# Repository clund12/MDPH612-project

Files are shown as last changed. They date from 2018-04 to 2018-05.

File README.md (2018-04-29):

MDPH612 TERM PROJECT
====================

# Towards a 4D breast phantom for Radiotherapy QA
## Translation of breathing trace data into mechanical motion

### Project Outline

The goal of this work is to design an open-source, easy-to-construct 4D breast phantom model that could be constructed by medical physicists for motion-tracking and, potentially, dosimetry of CyberKnife treatments.  A list of materials required by any interested physicists is provided below, as are the scripts needed to interact with the equipment and the files needed for the 3D printing of some components.  Initially, the goal is to construct a proof-of-principle 2D model that accurately translates the time and spatial (1D) information of a Varian RPM breathing trace into mechanical motion.

### Equipment

- Raspberry Pi 3
- NEMA 17 Stepper motor
- Archimedes screw, washer, and connector to motor
- Bearing to hold screw at other end
- Texas Instruments DRV8825 Stepper Motor Controller IC
- 3D printer capable of printing parts up to approximately 30 cm in length
- Electrical components:
    - 10-12 V power supply
    - Multimetre
    - Breadboard, wires, etc.

### Aims

- Write a script to control the motor via the RPi
- Connect the electronics, RPi, and motor and test the script
- Design a 3D model of the support and rails needed to house the mechanical
  components
- Assemble mechanics/electronics with housing and connect motor to screw
- Improve script to handle errors and make it more user-friendly
- Extend principles to include a second spatial dimension
- Still to come..

### Progress

- All electronics, mechanical, and printed components assembled properly
- The script interfaces the RPi, driver, and motor correctly
    - Able to handle complex input behaviour
    - Spatial accuracy is very high
    - Platform cannot be extended past the physical bounds of the rails and is
      always returned to the centre
    - Useful errors are returned when users input improper files

### Issues

- Temporal accuracy must be addressed
- Friction along the rails must be reduced
- Errors should be returned when movements are beyond the capacity of the motor
- Next iteration of housing will need to be made more robust

### Authors

- Chris Lund
- Veng Jean Heng

### Acknowledgements

- Dr. Francois DeBlois
- McGill MPU
- rdagger68 (circuitry tutorial)

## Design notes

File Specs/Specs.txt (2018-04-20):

Screw's spec:
(https://www.pololu.com/product/2268/specs)
Pitch = 2 mm, 4 Threads -> 8 mm per rotation
Pin of motor: (https://i.stack.imgur.com/2vYSy.png)
https://www.pololu.com/product/2688/pictures

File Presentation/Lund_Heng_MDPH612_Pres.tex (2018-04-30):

\documentclass{beamer}
\usetheme{CambridgeUS}
%\usecolortheme[RGB={0,0,0}]{structure}
\usepackage{pgfpages}
\usepackage{hyperref}
\usepackage{pdfpc-commands}
\usepackage{epstopdf}
\usepackage{array}
\usepackage{svg}
\usepackage{graphicx}
\usepackage{amsmath}
\usepackage{amsfonts}
\usepackage{amssymb}
\usepackage{bm}
\usepackage{ulem}
\usepackage{xfrac}
\usepackage{dcolumn}
\usepackage{multirow}
\usepackage{caption}
\usepackage{color}
\usepackage{listings}
\usepackage{gensymb}
\usepackage{appendixnumberbeamer}
\usepackage{animate}
%\setbeameroption{show notes}
%\setbeameroption{show notes on second screen=right}
\setbeamertemplate{bibliography item}[text]
%\renewcommand{\arraystretch}{1.5}
\newcommand{\mytilde}{\raise.17ex\hbox{$\scriptstyle\mathtt{\sim}$}}
\title[4D Breast Phantom]{Towards a 4D Breast Phantom for Radiotherapy QA}
\author[C. Lund, V.J. Heng]{Chris Lund and Veng Jean Heng}
\titlegraphic{}
\institute[McGill MPU]{Medical Physics Unit \\ Department of Oncology, McGill University}
\date{\today}
%\logo{\includegraphics[scale=0.2]{/home/chris/Documents/McGill/MDPH603/McGill_logo.png}}

\begin{document}

\begin{frame}

    \maketitle

\end{frame}

\begin{frame}

    \frametitle{Motivation}

    \begin{columns}
        \begin{column}{0.5\textwidth}
            \begin{itemize}
                \item Motion in imaging and treatment can pose an issue..
                    \begin{itemize}
                        \item Breath hold/gated treatments
                        \item CyberKnife motion-tracking
                        \item Motion artifacts in IGRT
                    \end{itemize}
                \vspace{1em}
                \item Currently, only available QA phantom is by QUASAR
                    \begin{itemize}
                        \item Very expensive
                        \item Not full 4D capabilities
                    \end{itemize}
                    \vspace{1em}
                \item Desire for more accessible alternative
            \end{itemize}
        \end{column}
        \begin{column}{0.5\textwidth}
            \vspace*{-1.5em}
            \begin{figure}[h]
                \centering
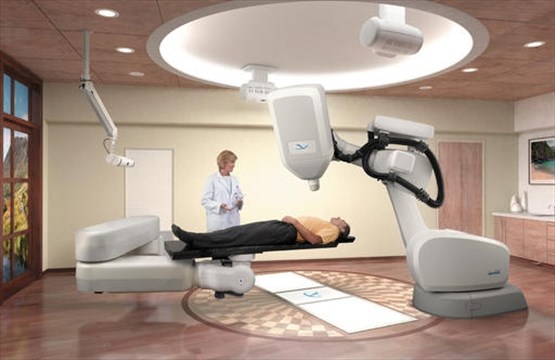
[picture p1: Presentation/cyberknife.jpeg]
                
            \end{figure}
            \vspace*{-2em}
            \begin{figure}[h]
                \centering
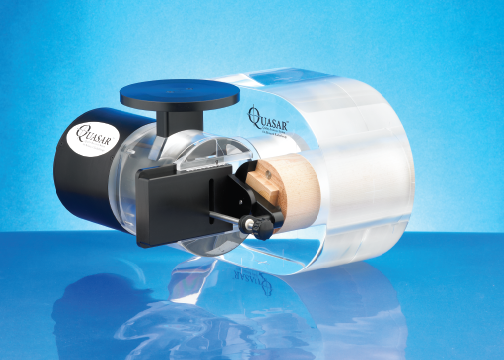
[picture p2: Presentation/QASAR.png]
                
            \end{figure}
        \end{column}
    \end{columns}

\end{frame}

\begin{frame}

    \frametitle{Overview of Project}

    \begin{itemize}
        \item Want to
            \begin{itemize}
                \item Take in a breathing trace
                \item Convert it into mechanical motion
            \end{itemize}
            \vspace{1em}
        \item Needs to be
            \begin{itemize}
                \item Standalone
                \item ``Perfect'' temporal and spatial accuracy
                \item Open-source and cheap
            \end{itemize}
            \vspace{1em}
        \item How to?
            \begin{itemize}
                \item Raspberry Pi $\rightarrow$ Stepper motor
                \item Rotational motion $\rightarrow$ Linear motion
            \end{itemize}
    \end{itemize}

\end{frame}

\begin{frame}

    \frametitle{Circuitry}

        \begin{figure}
            \centering
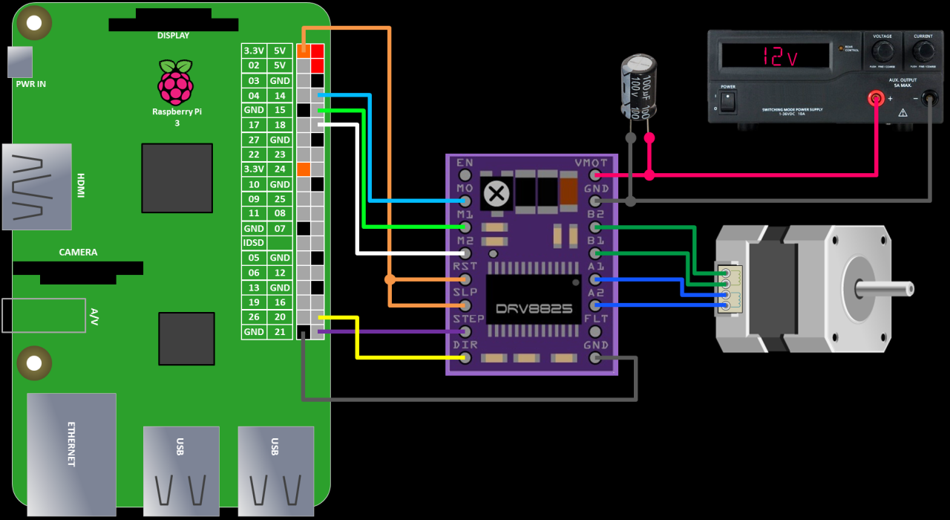
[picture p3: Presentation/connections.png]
            
        \end{figure}

\end{frame}

\begin{frame}

    \frametitle{Stepper Motors}
    \begin{columns}
        \begin{column}{0.5\textwidth}

            \begin{itemize}
                \item Step-based
                    \begin{itemize}
                        \item Define the angle of rotation
                        \item Perfect spatial accuracy
                    \end{itemize}
                    \vspace{1em}
                \item PWM-based
                    \begin{itemize}
                        \item Define the frequency of rotation
                        \item Perfect temporal accuracy
                    \end{itemize}
            \end{itemize}
        \end{column}
        \begin{column}{0.5\textwidth}
            \begin{figure}
                \centering
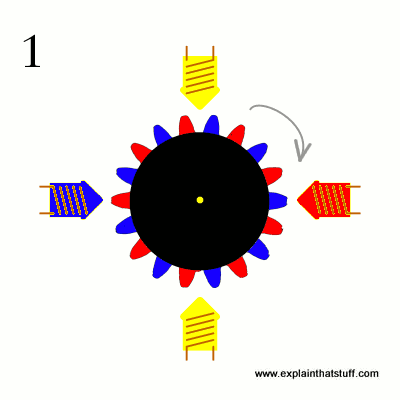
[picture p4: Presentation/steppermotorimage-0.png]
                
            \end{figure}
            \begin{figure}
                \centering
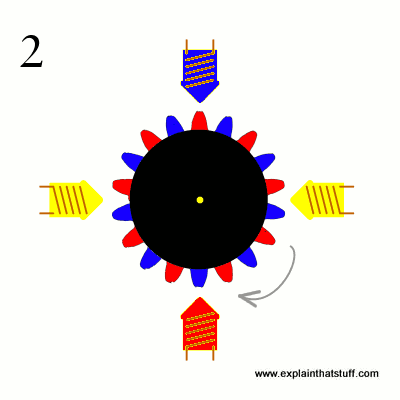
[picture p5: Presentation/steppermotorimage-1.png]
                
            \end{figure}
        \end{column}
    \end{columns}

\end{frame}

\begin{frame}

    \frametitle{Visit our page!}

    \centering
    \url{https://github.com/clund12/MDPH612-project}

\end{frame}

\end{document}

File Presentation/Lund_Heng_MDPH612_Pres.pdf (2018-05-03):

## Towards a 4D Breast Phantom for Radiotherapy QA

Chris Lund and Veng Jean Heng

Medical Physics Unit
Department of Oncology, McGill University

April 30, 2018

C. Lund, V.J. Heng (McGill MPU) | 4D Breast Phantom | April 30, 2018 | 1 / 6

## Motivation

Motion in imaging and
treatment can pose an issue.. Breath hold/gated treatments CyberKnife motion-tracking Motion artifacts in IGRT

Currently, only available QA phantom is by QUASAR
Very expensive
Not full 4D capabilities

Desire for more accessible alternative

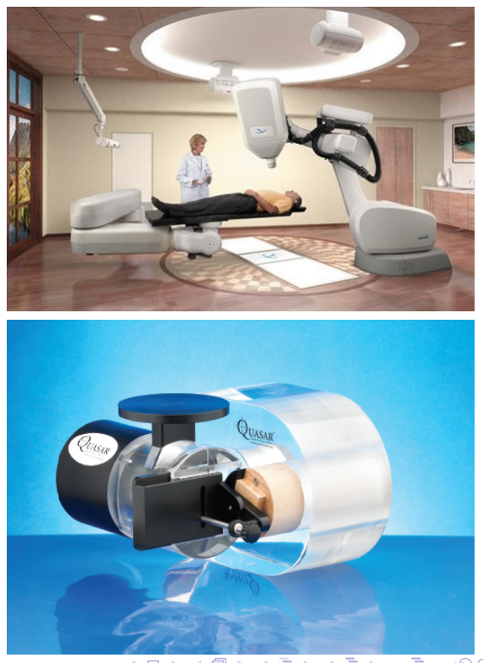
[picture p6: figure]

C. Lund, V.J. Heng (McGill MPU) | 4D Breast Phantom | April 30, 2018 | 2 / 6

## Overview of Project

Want to
Take in a breathing trace
Convert it into mechanical motion

Needs to be
Standalone
“Perfect” temporal and spatial accuracy Open-source and cheap

How to?
Raspberry Pi → Stepper motor Rotational motion → Linear motion
C. Lund, V.J. Heng (McGill MPU) | 4D Breast Phantom | April 30, 2018 | 3 / 6

## Circuitry

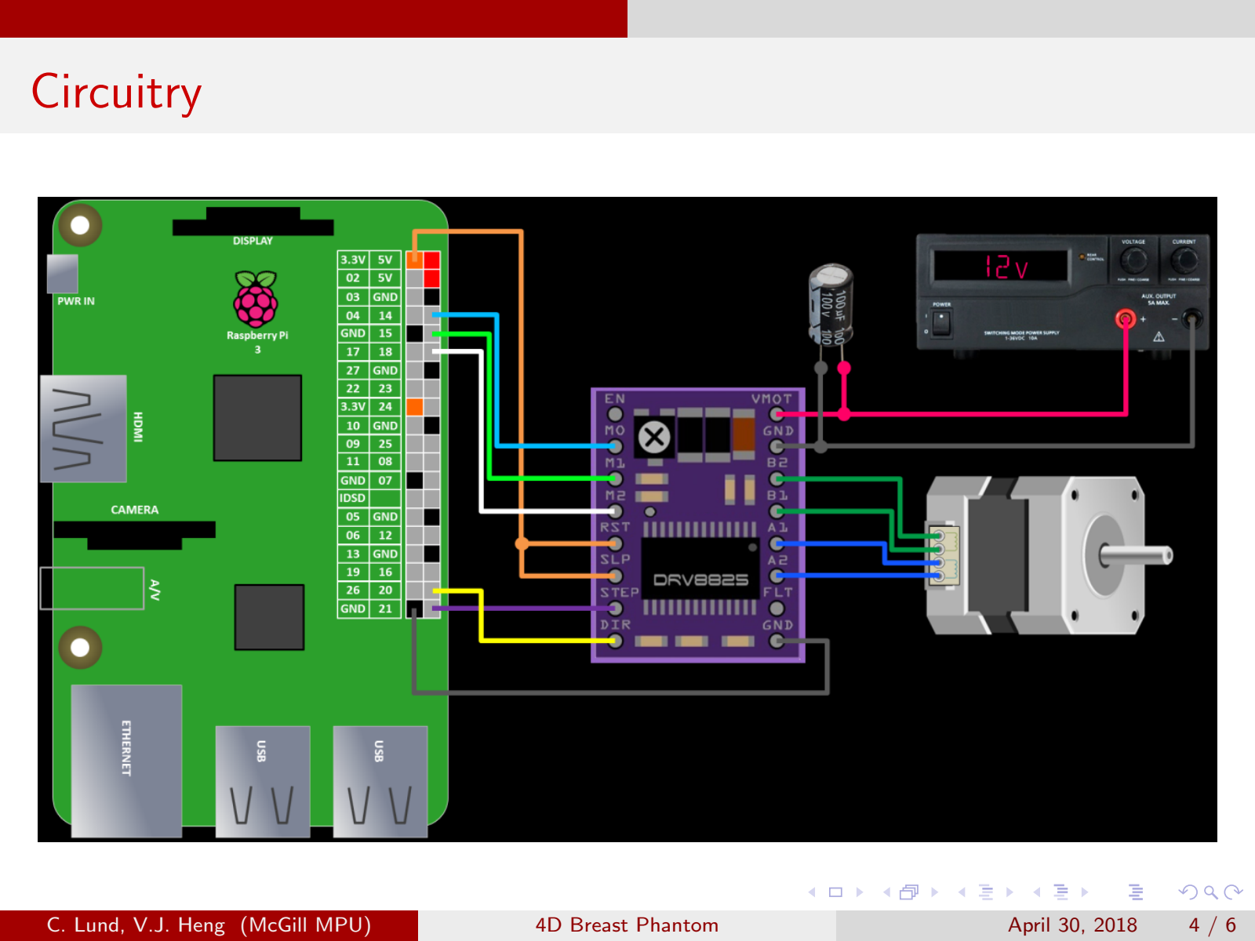
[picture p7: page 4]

C. Lund, V.J. Heng (McGill MPU) | 4D Breast Phantom | April 30, 2018 | 4 / 6

## Stepper Motors


Step-based
Define the angle of rotation Perfect spatial accuracy

PWM-based
Define the frequency of
rotation
Perfect temporal accuracy

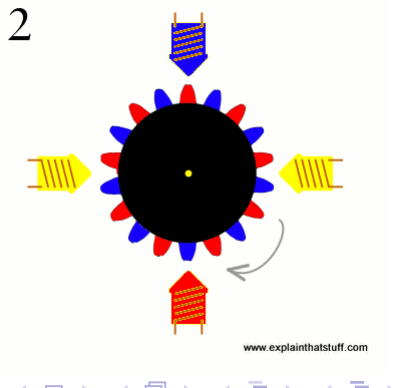
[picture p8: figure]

C. Lund, V.J. Heng (McGill MPU) | 4D Breast Phantom | April 30, 2018 | 5 / 6

## Visit our page!

https://github.com/clund12/MDPH612-project

C. Lund, V.J. Heng (McGill MPU) | 4D Breast Phantom | April 30, 2018 | 6 / 6

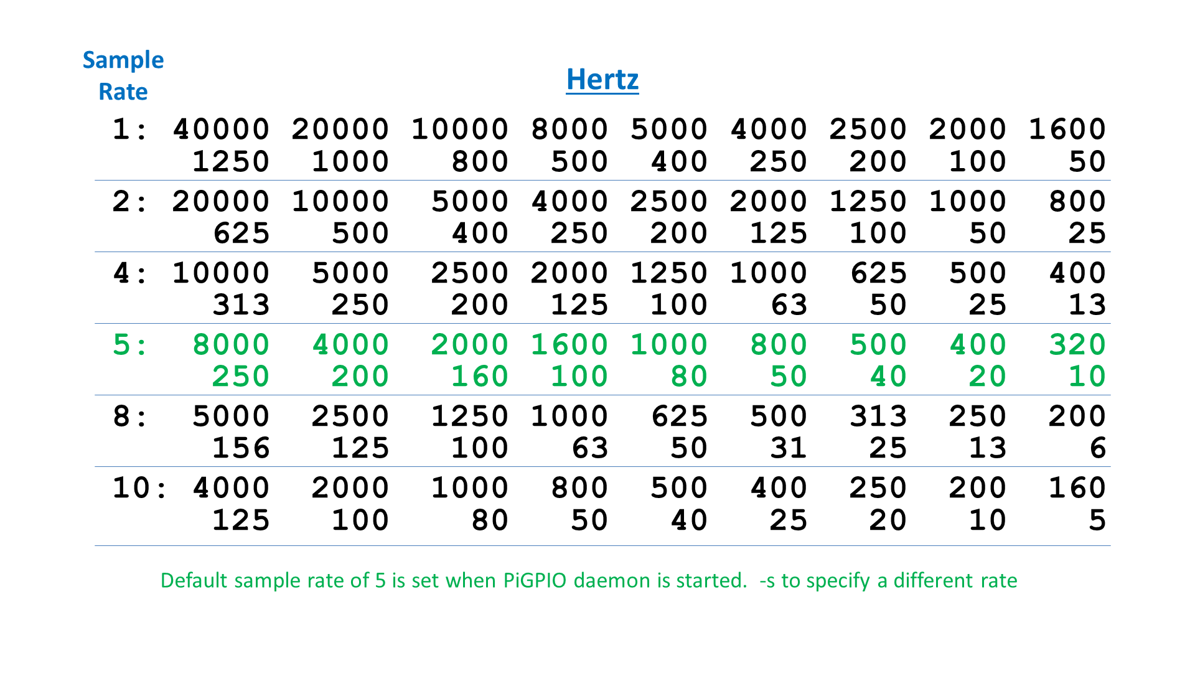
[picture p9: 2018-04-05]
Specs/PiStepperFreq.png

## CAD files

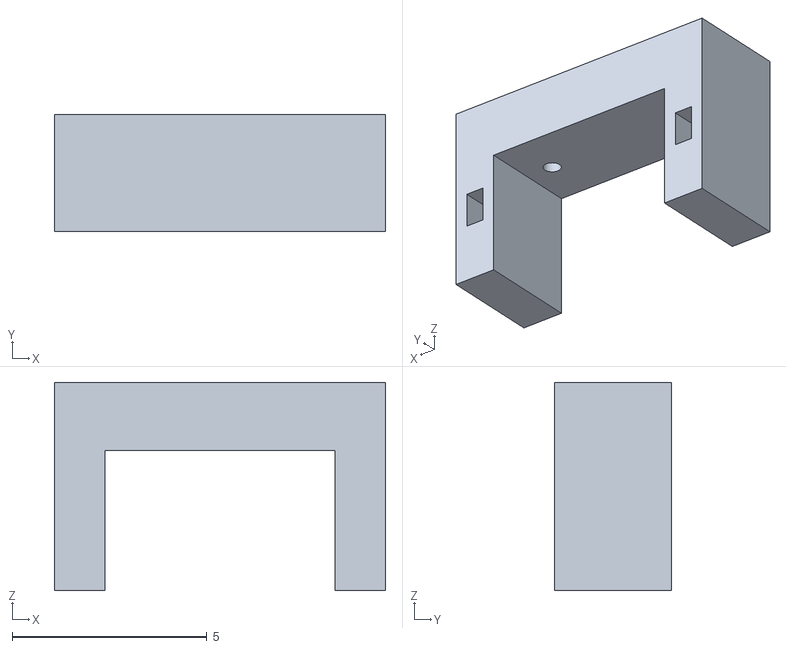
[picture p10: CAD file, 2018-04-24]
3D-Model/BearingCase.stl
8.50 x 3.00 x 5.35

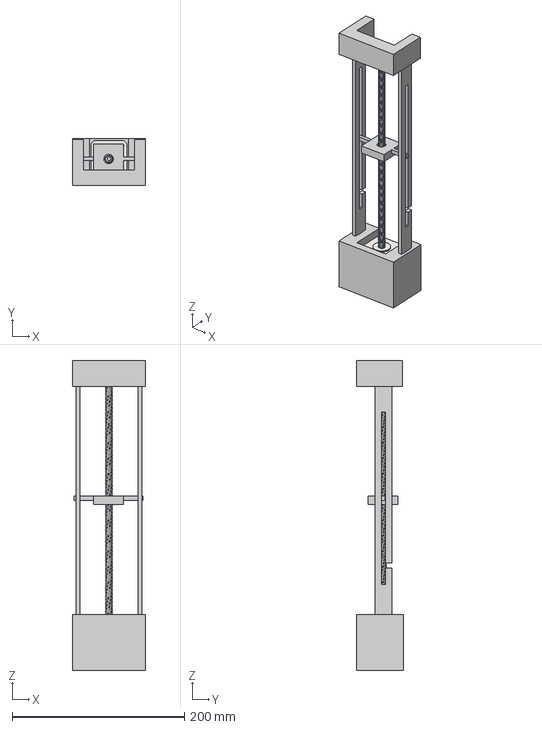
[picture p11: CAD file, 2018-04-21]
3D-Model/Combined v5.iges
85.0 x 55.0 x 360.0 mm

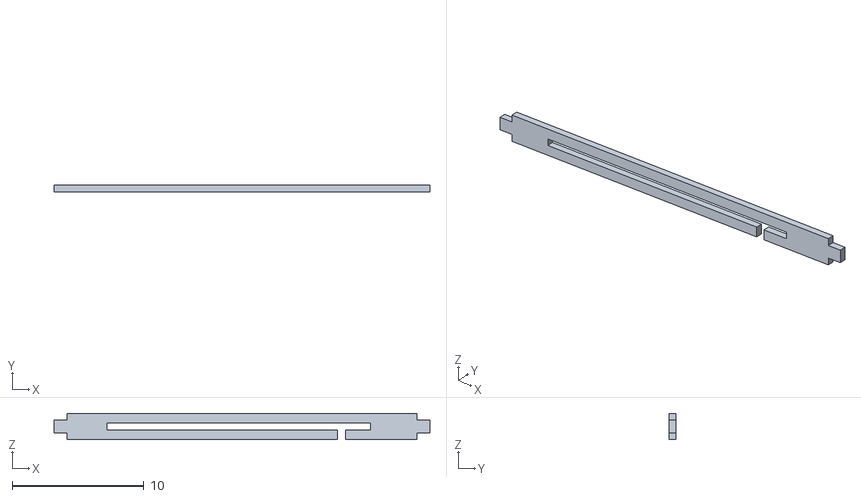
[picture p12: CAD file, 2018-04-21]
3D-Model/Rail.stl
28.5 x 0.5 x 2.00

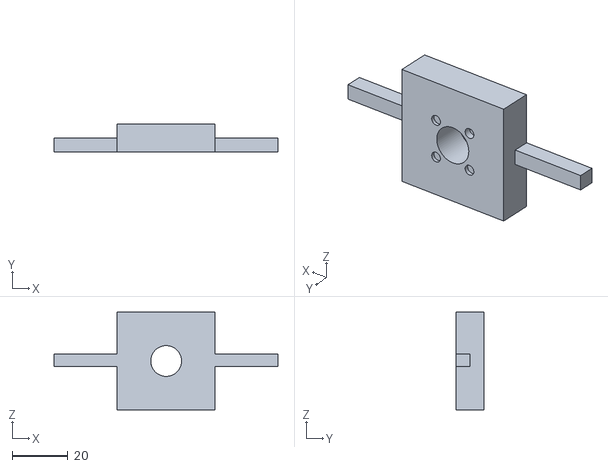
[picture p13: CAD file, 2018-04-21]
3D-Model/TravellingNut.stl
80.0 x 10.0 x 35.0

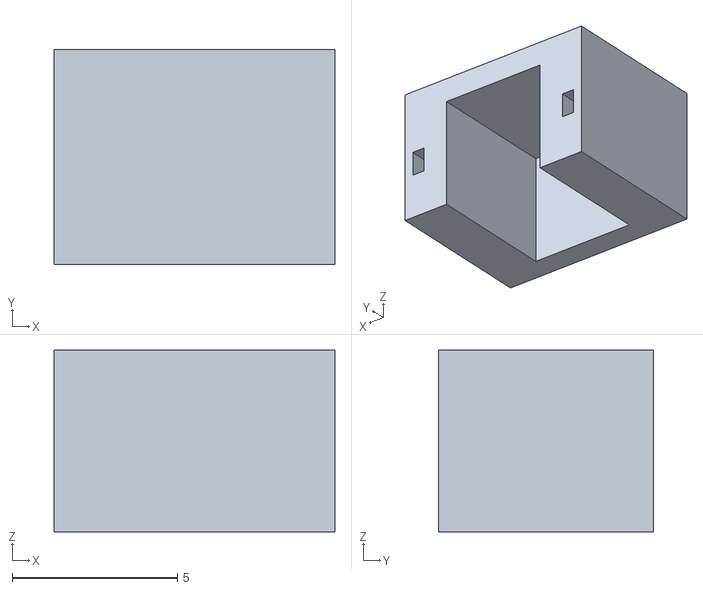
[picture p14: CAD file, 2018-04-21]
3D-Model/MotorCase.stl
8.50 x 6.50 x 5.50

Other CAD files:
3D-Model/Bearing Case v15.f3d
3D-Model/Motor casing v5.f3d
3D-Model/TravelingNut v5.f3d
3D-Model/rail.f3d

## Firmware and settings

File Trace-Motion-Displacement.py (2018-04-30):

import sys
import numpy as np
import csv
import itertools
import RPi.GPIO as GPIO
from time import time,sleep

#### This file must be run with a data file 
#### e.g. >> python FiletypeInputTest.py example.txt

##############################################################################
#### Set up GPIO pins and microstep resolution

# Convert direction from +/- to 1/0 for clockwise/counter-clockwise
def rot_direct(x):

    if np.sign(x) == 1:
        return 1
    else:
        return 0


DIR = 20          # Direction GPIO Pin
STEP = 21         # Step GPIO Pin
MODE = (14,15,18) # Microstep Resolution GPIO pins

GPIO.setmode(GPIO.BCM)      # Broadcom memory
GPIO.setup(DIR, GPIO.OUT)   # Sets direction pin to an output
GPIO.setup(STEP, GPIO.OUT)  # Sets step pin to an output
GPIO.setup(MODE, GPIO.OUT)


RESOLUTION = {'1': (0,0,0),
        '0.5': (1,0,0),
        '0.25': (0,1,0),
        '0.125': (1,1,0),
        '0.0625': (0,0,1),
        '0.03125': (1,0,1)}
RES = '0.25'

GPIO.output(MODE,RESOLUTION[RES])

################################################################################
# Read in data file, ensures it is a 2 column csv or txt file with equal lengths
# Import the data if it matches the criteria, raise an error otherwise
# PLEASE DELETE ANY AND ALL HEADERS

# First, read in data file entered during function call
f = open(sys.argv[1],'r')


# Check file extension in a case-insensitive manner
if sys.argv[1].lower().endswith('.csv'):
        
    # If .csv, use commas to split values and lines
    d = ','


elif sys.argv[1].lower().endswith('txt'):

    # If .txt, use tabs to split values and lines
    d = '\t'

    # Remove blank lines
    lines = f.readlines()

    with open(sys.argv[1],'w') as f:
        lines = filter(str.strip, lines)
        f.writelines(lines)


else: 
    raise ValueError("This is not a .csv or .txt file")

with open(sys.argv[1],'r') as f:

    # Use csv reader tool to make sure the number of columns is 2
    # Itertools.tee splits the single iterable output by csv reader into
    # multiple iterables
    rows, columns = itertools.tee(csv.reader(f, delimiter=d,
        skipinitialspace=True))


    # Read first line and count columns 
    if len(next(rows)) == 2:
        # Go back to beginning of file
        f.seek(0)

        # The file gives a list of values like ['t1,z1\n','t2,z2\n',etc.]
        # Where t = time (s), z = cranial-caudal displacement (cm)
        # Create new list of (t1,z1),(t2,z2), etc. tuples
        tz = []
        for line in f:
            thistz = line.split(d)
            tz.append(thistz)


        # Make sure that itertools does not hold rows in memory
        del rows


    else:
        raise ValueError("This file is not 2 columns")


# Try to convert t, z into lists of numbers and replace commas with periods
# Otherwise, raise an error
try:
    # First, separate list of tuples into lists of just t, z
    t, z = zip(*tz)
    
    # Now replace ',' with '.' and convert to float
    t = list(map(lambda i: float(i.replace(',', '.')), t))
    z = list(map(lambda i: float(i.replace(',', '.')), z))

except:
    raise ValueError("This file contains non-numerical data and/or blank spaces")


################################################################################
### Calculate displacements from trace position data

# Create list of displacements and time intervals (simplest method)
displacements = []
delta_t = []

for i, val in enumerate(z[0:-1]):

    dis = z[i+1] - z[i]
    del_t = t[i+1] - t[i]
    displacements.append(dis)
    delta_t.append(del_t)

spr = 200                 # steps per revolution = 200 - from NEMA 17 spec sheet
micro = 1/float(RES)      # Number of microsteps per full step
step_count = micro*spr    # Total number of microstep per revolutions


# Rotation angle (microsteps) = step count (microsteps/rev) * linear displ. (cm) / (0.8 cm/rev)
theta = list(map(lambda i: step_count*i/0.8, displacements))

# Can only input positive frequencies, so take absolute value of every omega
mag_theta = list(map(lambda i: abs(int(round(i))),theta))

# Also need the directions: clockwise (1) if positive, counterclockwise (0) if negative
directions = list(map(rot_direct, theta))

# Finally, need positive or negative direction info to keep track of position
sign = list(map(np.sign, theta))

# Define maximum position to be 8 cm in either direction, so platform is not overextended
max_pos = step_count*8/0.8

# Define delay to be (half, see below) the time taken to rotate a microstep
delay = []

# If next time interval requires 0 step, delay is simply set to be equal to the
# full time interval  
for i, val in enumerate(mag_theta):
    if val == 0:
        delay.append(delta_t[i])
    else:
        delay.append(delta_t[i]/val)


# Divide delay by 2 because delays are set twice per step
delay = np.divide(delay,2)

# Minimum allowable delay defined by max frequency 
# (1 / 1 kHz * 2 * # of micro steps per full step)
min_delay = 1/(2*38000*micro)
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

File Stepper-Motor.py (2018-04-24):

import numpy as np
from time import sleep
import RPi.GPIO as GPIO # Can ONLY be run on a RPi!

DIR = 20     # Direction GPIO Pin
STEP = 21    # Step GPIO Pin
SWITCH = 16  # GPIO Pin of Switch
CW = 1       # Clockwise Rotation
CCW = 0      # Counterclockwise Rotation
SPR = 200     # Steps per Revolution (Checked according to NEMA 17 spec sheet)

GPIO.setmode(GPIO.BCM)      # Broadcom memory
GPIO.setup(DIR, GPIO.OUT)   # Sets direction pin to an output
GPIO.setup(STEP, GPIO.OUT)  # Sets step pin to an output
GPIO.output(DIR, CW)        # Sets initial direction to clockwise

step_count = SPR    # Set initial test to a single rotation
delay = 0.005     # (1s / 200) - rotation will take 1 second if no delay

for x in range(step_count):     # Counts the 200 steps
    GPIO.output(STEP, GPIO.HIGH)# Toggles step pin high
    sleep(delay)                # Wait duration of step
    GPIO.output(STEP, GPIO.LOW) # Toggles step pin low
    sleep(delay)                # Wait again: Pulsed, 2s for full rotation

sleep(.5)            # delay for half of a second after rotation(s)
GPIO.output(DIR,CCW) # Set direction to counterclockwise

# Go through rotation loop again with the new direction
# This might be where we can condense the program -> placing the GPIO.output into a conditional for loop will allow a continuous change as we run through a data set - as long as the delays aren't too short! This would then mean that we will always have to run it in some sort of pulsed mode, depending on how fast the loop runs through -> probably not a problem
for x in range(step_count):
    GPIO.output(STEP, GPIO.HIGH)
    sleep(delay)
    GPIO.output(STEP, GPIO.LOW)
    sleep(delay)
GPIO.cleanup()
###### This is from the first half of the tutorial - microstepping not included because I want to get everything set up in the simplest way before we play around with it. I'm going to focus on the velocity file now. It might actually be worth leaving this file as is and making a new one, so we can just check the motor with this one, then with a microstepping file, and then have a more complex file ready to go.

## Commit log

2018-03-29 New files
    [trace.csv]
2018-04-03 Slight change to TracetoVelocities.py
2018-04-04 Added rail model
    [BarrelHolder.stl, Bottom.stl, NeedleHolder.stl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]
2018-04-04 Added platform model
    [Platform.stl]
2018-04-11 Added specs and borrowed text file, added comment in motor-velocities
2018-04-20 created 3D model folder
    [TravelingNut v3.iges, rail v1.iges]
2018-04-21 Finished 3D model
    [Bearing Case v15.f3d, BearingCase.stl, Combined v5.iges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]
2018-04-24 Changed models
    [BarrelHolder.stl, Bearing Case v15.f3d, BearingCase.stl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]
2018-04-24 added test scripts for motor
2018-04-25 Added functionality/errors for input files
    [Trace-Motion.py]
2018-04-26 Added trace
2018-04-26 Deleted redundant/unnecessary files
    [tracevelocities.csv]
2018-04-26 Fixed Stepper-Test.py
2018-04-26 New trace.csv
    [trace.csv]
2018-04-26 Modified trace.csv
    [trace.csv]
2018-04-26 New spintrace.csv
    [spintrace.csv]
2018-04-26 new square trace
    [squaretrace.csv]
2018-04-27 added comments in Stepper-Test
2018-04-27 Changes to Trace-motion
2018-04-27 Merged pi-motion and trace-motion
2018-04-28 New example files, folder structure
    [spintrace.csv, squaretrace.csv, trace.csv]
2018-04-29 Reorganized files
    [spintrace.csv, squaretrace.csv, trace.csv]
